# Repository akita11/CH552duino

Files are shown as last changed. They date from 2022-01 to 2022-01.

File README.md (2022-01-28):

# CH552duino

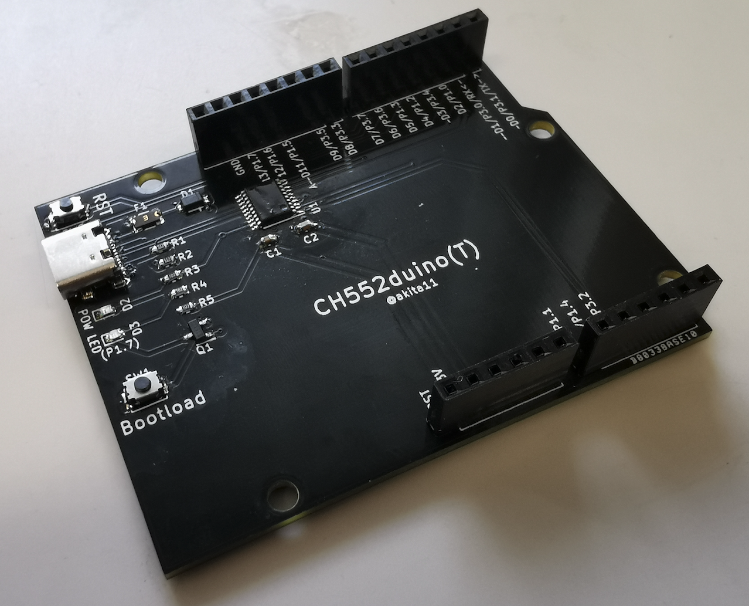
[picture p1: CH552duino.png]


[WCH(南京沁恒微电子股份有限公司)](http://wch-ic.com/)の8ビットマイコン[CH552](http://wch-ic.com/products/CH552.html)を使った、Arduino UNO型のマイコンボードです。
主な特徴は以下のとおりです。

- Arduino UNO型
- [ArduinoIDEなどでプログラム開発が可能](https://qiita.com/akita11/items/d7baed4ca3c06e292637)
- USBペリフェラル（キーボードやUSBメモリなど）として動作可能
- USB Type-Cコネクタ

またArduinoUNOとは、以下のような違いがあります。
- 一部ピンの機能が異なる
- 一部未接続のソケット端子がある
- +3.3V出力の電流供給能力は100mA程度（CH552内蔵レギュレータの性能）
- リセット(RST)は正論理で、"1"でリセット
- +5V端子に、外部電源から+5Vを供給可能（内部にレギュレータはないので、+5Vを超える電圧は不可）

基板上の"LED"（オレンジ）はP1.7で駆動できます。

## ピン配置

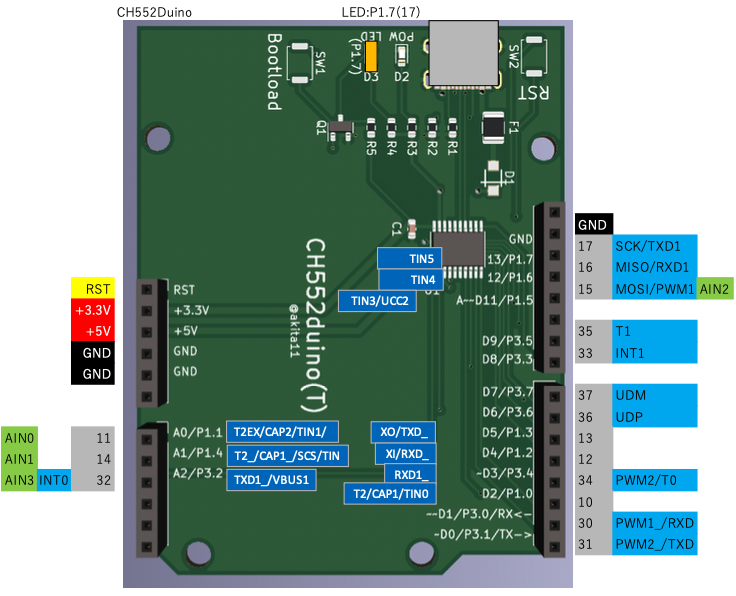
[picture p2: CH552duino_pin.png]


## Author

Junichi Akita (@akita11) / akita@ifdl.jp

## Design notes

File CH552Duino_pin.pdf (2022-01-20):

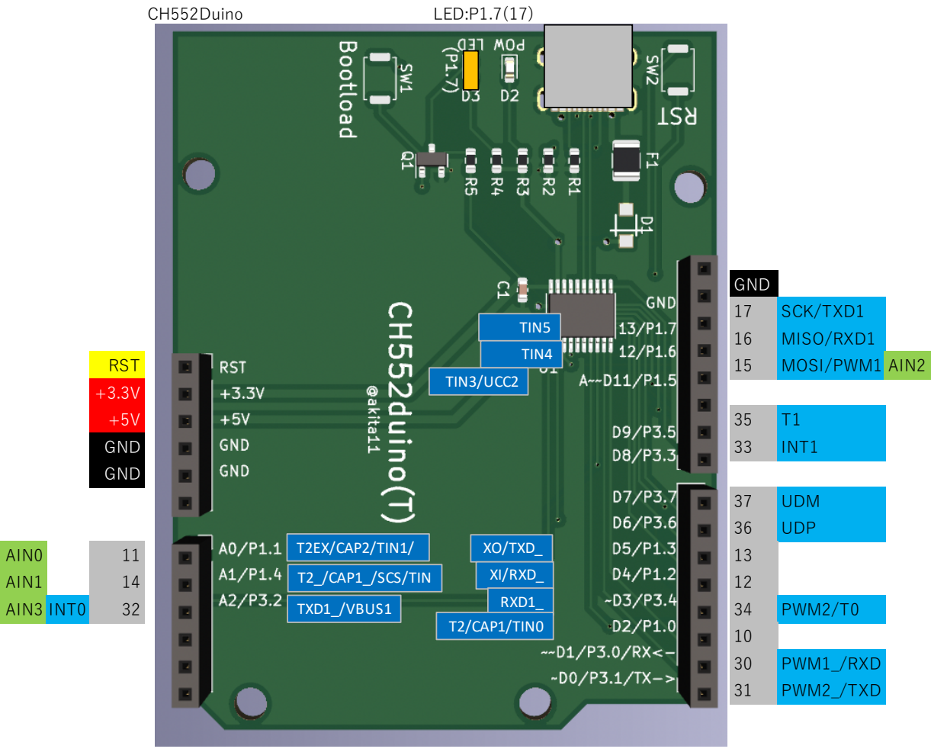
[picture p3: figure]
CH552Duino; LED:P1.7(17); GND; SCK/TXD1; MISO/RXD1; RST; MOSI/PWM1; AIN2; INT1; UDM; UDP; AIN0; AIN1; AIN3; INT0; PWM2/T0; PWM1_/RXD; PWM2_/TXD; T2EX/CAP2/TIN1/ T2_/CAP1_/SCS/TIN; TXD1_/VBUS1; XO/TXD_ XI/RXD_ RXD1_ T2/CAP1/TIN0; TIN5 TIN4; TIN3/UCC2

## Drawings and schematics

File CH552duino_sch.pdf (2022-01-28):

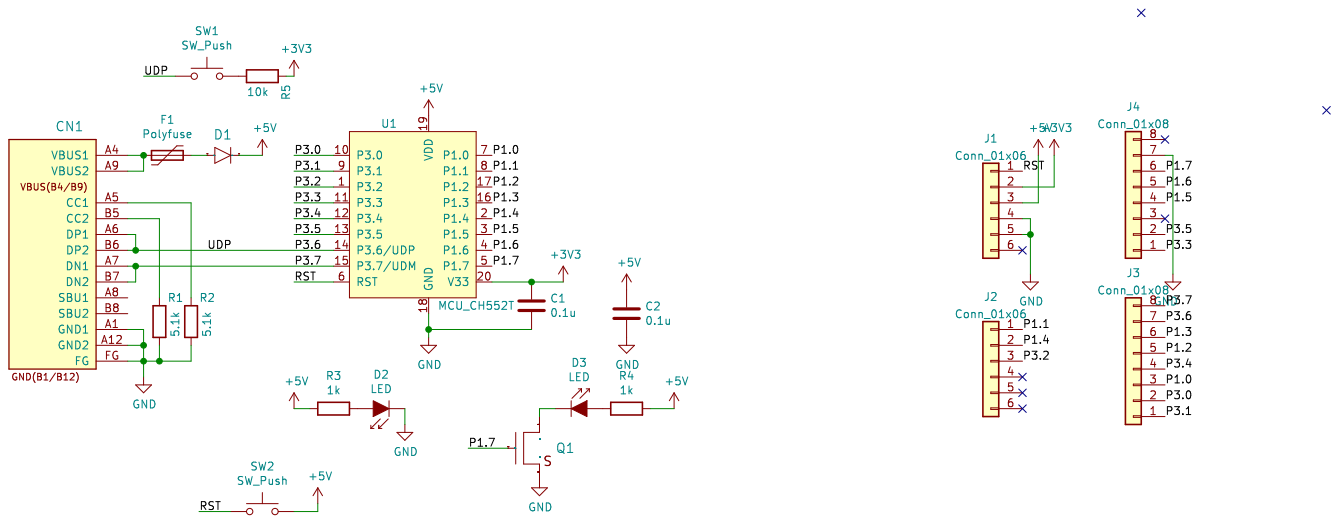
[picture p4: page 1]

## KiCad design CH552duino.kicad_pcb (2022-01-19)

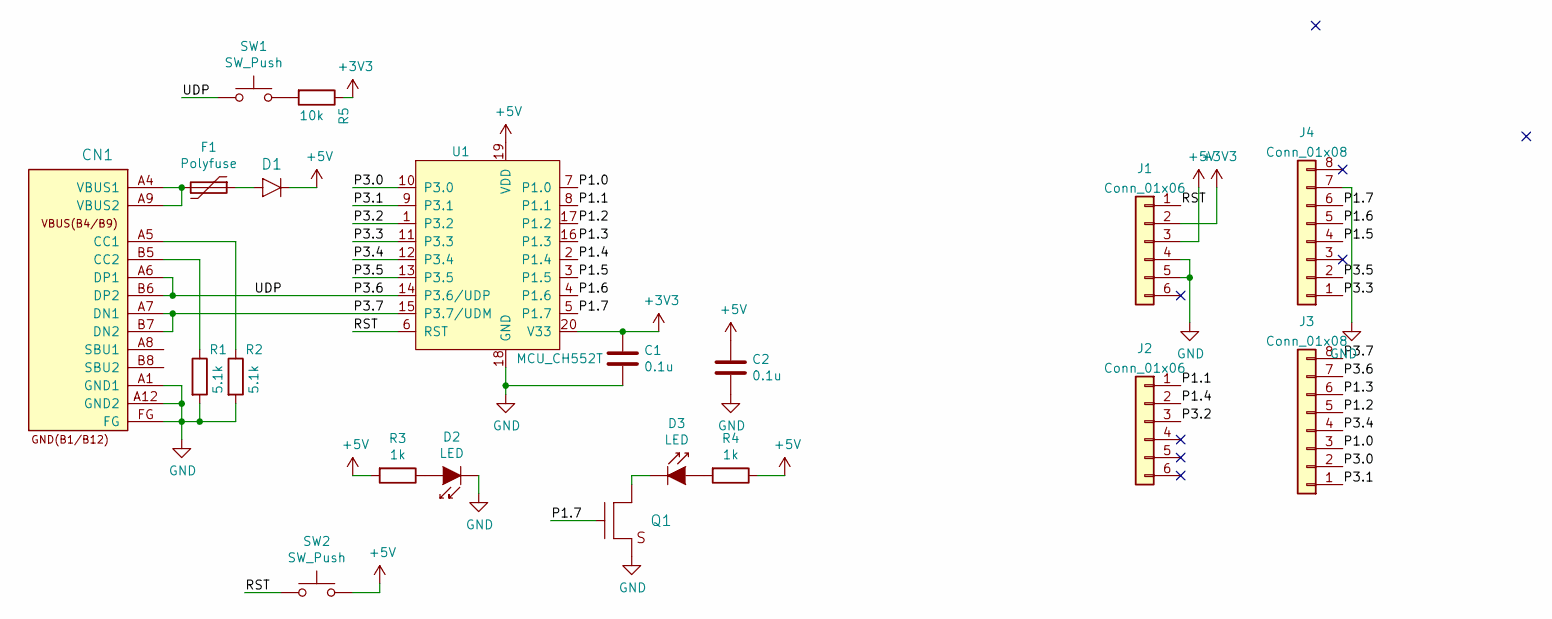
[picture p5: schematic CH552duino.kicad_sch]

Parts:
C1, C2: 0.1u; C_0603_1608Metric
CN1: CON_USB-C-16; USB-C_16P_TH
D1: DIODE; D_SOD123FL
D2, D3: LED; LED_0603_1608Metric
F1: Polyfuse; R_1210_3225Metric
J1, J2: Conn_01x06; PinSocket_1x06_P2.54mm_Vertical
J3, J4: Conn_01x08; PinSocket_1x08_P2.54mm_Vertical
Q1: TR_NMOS_IRLML6344; SOT-23
R1, R2: 5.1k; R_0603_1608Metric
R3, R4: 1k; R_0603_1608Metric
R5: 10k; R_0603_1608Metric
SW1, SW2: SW_Push; SW_Push_SPST_NO_Alps_SKRK
U1: MCU_CH552T; TSSOP-20_4.4x6.5mm_P0.65mm

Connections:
+3V3: C1.1, J1.2, R5.1, U1.20 (V33)
+5V: C2.1, D1.K, J1.3, R3.2, R4.1, SW2.2, U1.19 (VDD)
/P1.0: J3.3, U1.7 (P1.0)
/P1.1: J2.1, U1.8 (P1.1)
/P1.2: J3.5, U1.17 (P1.2)
/P1.3: J3.6, U1.16 (P1.3)
/P1.4: J2.2, U1.2 (P1.4)
/P1.5: J4.4, U1.3 (P1.5)
/P1.6: J4.5, U1.4 (P1.6)
/P1.7: J4.6, Q1.1 (G), U1.5 (P1.7)
/P3.0: J3.2, U1.10 (P3.0)
/P3.1: J3.1, U1.9 (P3.1)
/P3.2: J2.3, U1.1 (P3.2)
/P3.3: J4.1, U1.11 (P3.3)
/P3.4: J3.4, U1.12 (P3.4)
/P3.5: J4.2, U1.13 (P3.5)
/P3.6: CN1.A6 (DP1), CN1.B6 (DP2), J3.7, SW1.1, U1.14 (P3.6/UDP)
/P3.7: CN1.A7 (DN1), CN1.B7 (DN2), J3.8, U1.15 (P3.7/UDM)
/RST: J1.1, SW2.1, U1.6 (RST)
GND: C1.2, C2.2, CN1.A1 (GND1), CN1.A12 (GND2), CN1.FG, D2.1 (K), J1.4, J1.5, J4.7, Q1.2 (S), R1.2, R2.2, U1.18 (GND)
unnamed: CN1.A4 (VBUS1), CN1.A9 (VBUS2), F1.2
unnamed: CN1.A5 (CC1), R2.1
unnamed: CN1.B5 (CC2), R1.1
unnamed: D1.A, F1.1
unnamed: D2.2 (A), R3.1
unnamed: D3.1 (K), Q1.3 (D)
unnamed: D3.2 (A), R4.2
unnamed: R5.2, SW1.2

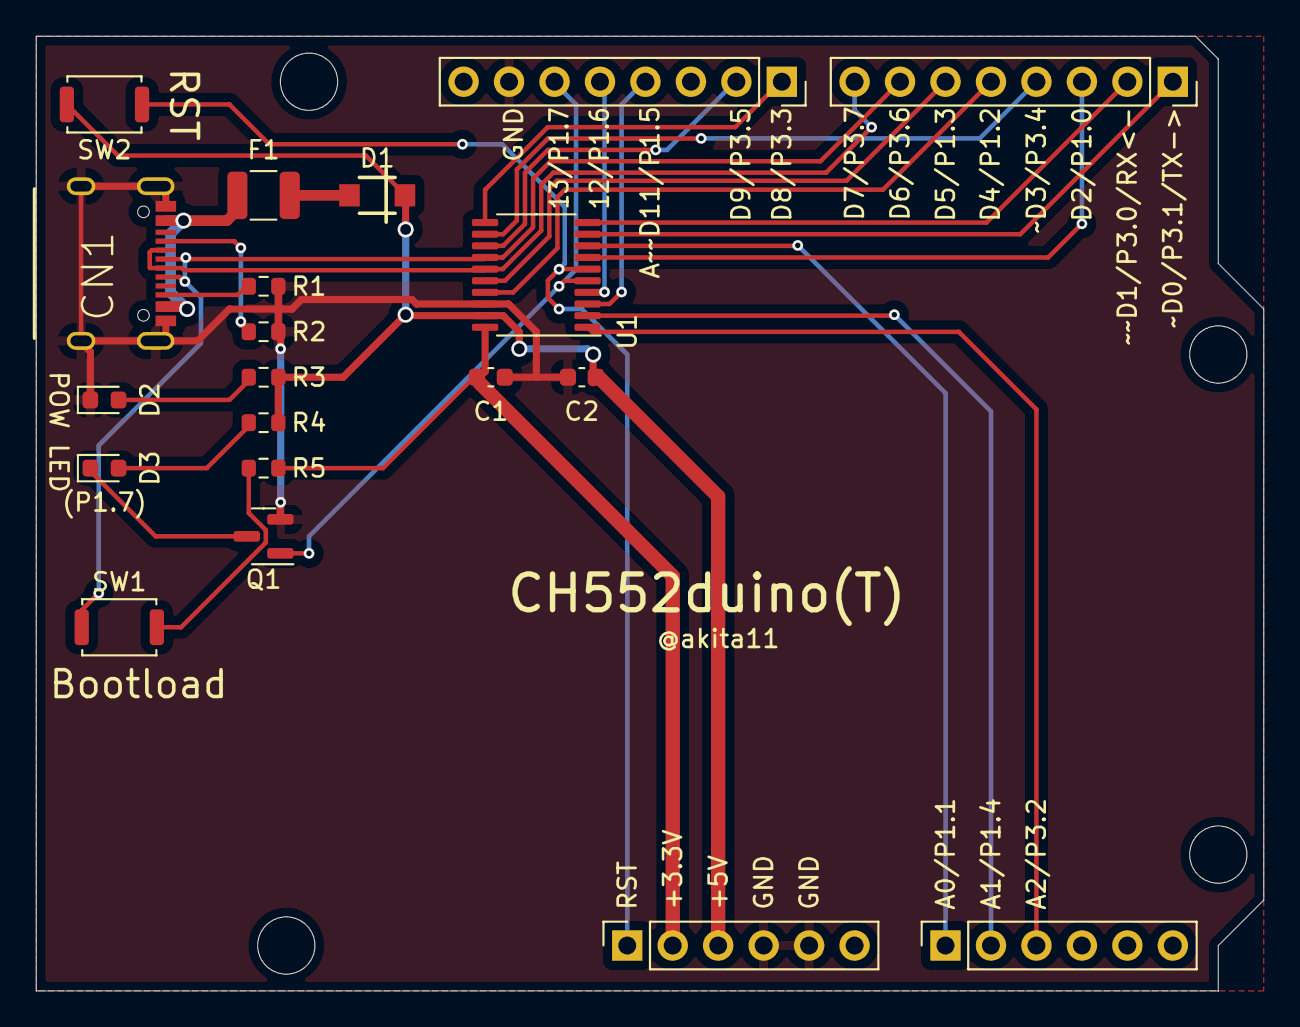
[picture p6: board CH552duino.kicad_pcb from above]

Board: 2 copper layers, 68.6 x 53.3 mm, 20 parts (0 on the bottom side), 28 nets.

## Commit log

2022-01-19 add pin map
2022-01-19 pin map
2022-01-20 update pin map
    [CH552Duino_pin.xlsx]
2022-01-20 resize pin map image
2022-01-20 外部電源について追記
2022-01-26 add LED pin
2022-01-28 +3.3V出力電流について追記
2022-01-28 add schematic
